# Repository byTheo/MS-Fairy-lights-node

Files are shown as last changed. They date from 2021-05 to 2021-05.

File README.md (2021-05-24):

# MS-Fairy-lights-node
A MySensors node for controlling Fairy Light strings. For making the mounting of the node into a light fixture easier, I've created a small PCB which supports NRF24L01+ radios only. I've kept the footprint of the PCB as small as I could, but I used through hole components in those places where the values depend on the type of fairy light you use. I used a 3 * AA battery version which outputs 5v to the fairy light string. In my case there was an 18ohm resistor between the chip that controls the fairy lights and the positive side of the fairy lights string itself.

# Hardware
It is of course not necessary to order a PCB but it makes life much easier than soldering it to a prototype board manually. This version supports up to 3 fairy lights - I have a seasonable version in my mind - and you can connect a tactile switch and rotary encoder to it for manual operation. I think that being able to manually operate smart lightning is a design must. Your phone battery can be empty or your HA system might be malfunctioning, so in those cases you need to be able to manually operate it.

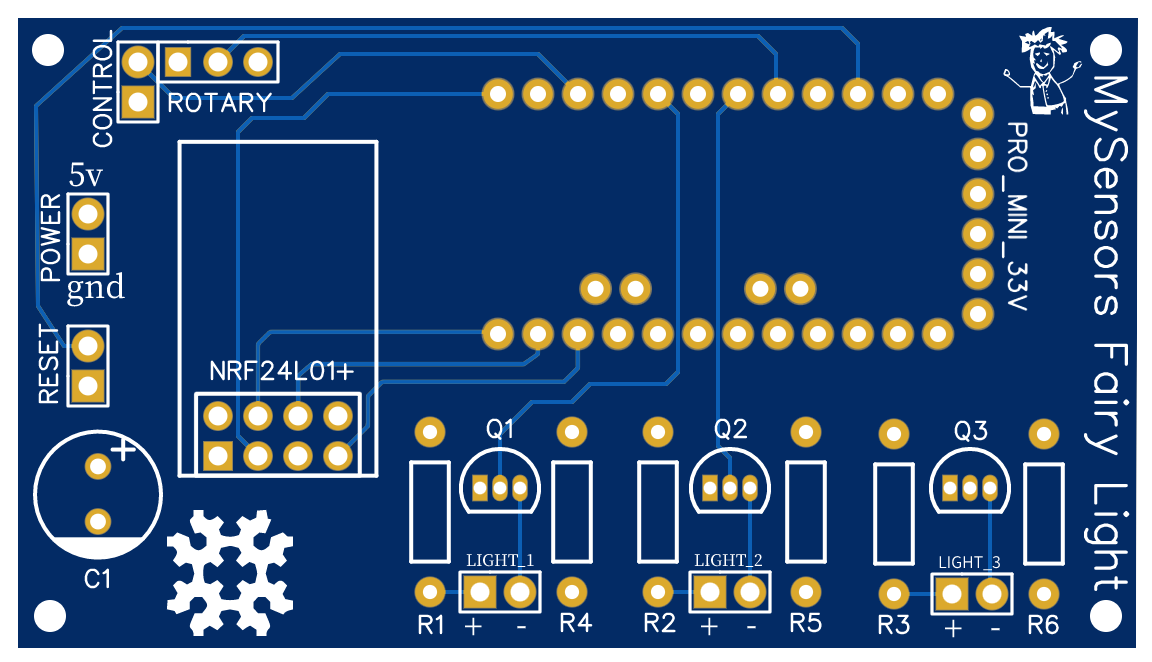
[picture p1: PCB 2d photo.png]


The mounting point for the NRF24L01+ radio is set inwards, this is so that an anglds female header (2*5p 2.54mm) can be mounted. I needed the radio to be mounted angled - but you will see that in a picture.

The Gerber files can be found in the root of this repository - otherwise I couldn't get the OpenHardware to detect my Gerver and design files. You can order 5 pcb's for around 15 euro's including shipping and tax.

The parts you need are:
- 1 x th 100uf capacitor for stabalising the NRF24L01+
- 1 x NRF24L01+ radio (for communicating over the MySensors network)
- 1 proMini 3.3v - they can be order cheaply on aliExpress or Ebat. I used the 3.3v version so that I didn't need to mount a separate power regulater for the radio on the PCB.

Depending on your FairyLight string, you need the following parts for each string:
- 1 2N7000 th - this mosfet can drive 200mA. My fairylights consume about 40mA at max brightness so more than sufficient
- 22 ohm th resistor - this is for current limiting the fairy light string it works on 2m fairy lights strings that are powered by 3  * AA batteries
- 1K pull down resistor (TH) - for pulling down the 2n7000's gate (10K or 100K is also fine)

Optional:
- either one tactile switch if you don't want to be able to manually dim the lights
- or a rotary encoder with tactile switch encorparated.

# Software
All the embedded software I created for this board is located in the *software* directory of this repository. The directory contains several sketches that utilize the PCB and transform it into:
- FairyLightLamp : a node with one single - dimmable - light which results in a nice ambiance.

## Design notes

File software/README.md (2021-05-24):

This directory contains several sketches for the Arduino IDE that use the MS Fairy lighs node pcb.

- FairyLightLamp : a sketchs that uses one fairly lights string. It's a dimmable light, with manual operation in the form of a rotary encoder with momentary switch. This type f lightning gives a nice ambiance but it's not suitable as a main light.

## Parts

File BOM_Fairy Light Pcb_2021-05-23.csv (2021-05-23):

ID | Name | Designator | Footprint | Quantity | Manufacturer Part | Manufacturer | Supplier | Supplier Part | Price | JLCPCB Part Class
1 | 100uF | C1 | CAP-TH_BD8.0-P3.50-D1.0-FD | 1 | 50V 100uF 8X12 | ValuePro | LCSC | C2749 | 0.0327
2 | Rotary encoder | H1 | HDR-TH_3P-P2.54-V | 1 | Header2.54mm 1*3P | BOOMELE | LCSC | C49257 | 0.0171 | Extended Part
3 | NRF24L01 | MK1 | WIRELM-SMD_NRF24L01 | 1 | NRF24L01+功率加强版绑定2.4Gwireless module | Ai-Thinker | LCSC | C90751 | 1.0655 | Extended Part
4 | Control switch | P2 | HDR-TH_2P-P2.54-V-M | 1 | 2.54mm 1*2P | ReliaPro | LCSC | C36717 | 0.0068
5 | 2.54mm 1*2P | P1,P3,P4 | HDR-TH_2P-P2.54-V-M | 3 | 2.54mm 1*2P | ReliaPro | LCSC | C36717 | 0.0068
6 | Power supply | P5 | HDR-TH_2P-P2.54-V-M | 1 | 2.54mm 1*2P | ReliaPro | LCSC | C36717 | 0.0068
7 | Reset switch | P6 | HDR-TH_2P-P2.54-V-M | 1 | 2.54mm 1*2P | ReliaPro | LCSC | C36717 | 0.0068
8 | 2N7000 | Q1,Q2,Q3 | TO-92-3_L4.9-W3.7-P1.27-L | 3 | 2N7000 | CJ | LCSC | C9114 | 0.0381 | Extended Part
9 | 18ohm | R1,R2,R3 | R_AXIAL-0.4 | 3
10 | 1K | R4,R5,R6 | R_AXIAL-0.4 | 3
11 | ARDUINO_PRO_MINI | U1 | ARDUINO_PRO_MINI | 1

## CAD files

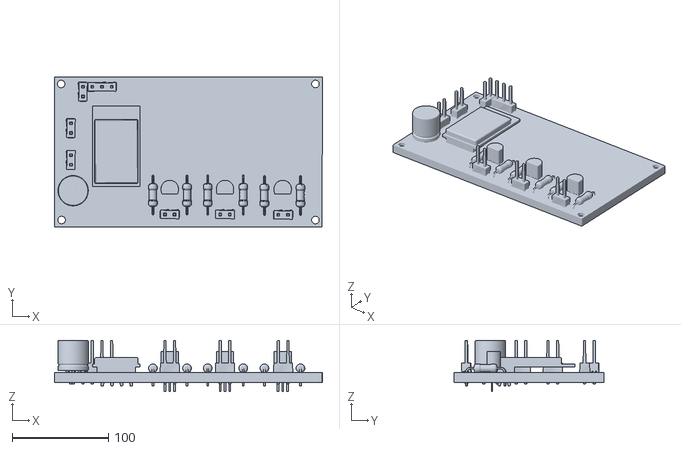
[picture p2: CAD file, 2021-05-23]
OBJ_MS_Fairy light - angled NRF24L01.obj
278.8 x 156.3 x 53.2

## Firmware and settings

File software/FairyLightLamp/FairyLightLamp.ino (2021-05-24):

/*
   My Sensos Sketch for the fair ligh based lamp, with smooth transition animation,

   By Theo
   January 4th 2021

   Revision
   01-04-2021 - initial version

   Future notes for myself - for a future project that uses a dimmer:
   - Handling Domoticz messages:
      only adjust brightness. Don't listen to brightness 0
      when V_LIGHT is 1, send current brightness. Domoticz turns on with 100% but it doesn't report it to the node
   - Handling user input:
      send current brightness when the lamp is turned on after sending V_LIGHT 1 ( "1" is on and "0" is off )
      send new brightness after user changes it.
*/

#include <Bounce2.h>
#include <Encoder.h>
#include "ledAnimation.h"
#include "multiClick.h"
#include "config.h"

const uint8_t POWER_SWITCH_PIN = 7; // Interupt pin so the sketch can wake up
const uint8_t LEDSTRING_PIN = 5; // Interupt pin so the sketch can wake up
const uint8_t ENCODER_FIRST_PIN = 2; // The first pin of the encoder, we use an interrupt pin for faster reading
const uint8_t ENCODER_SECOND_PIN = 4; // The second pin of the encoder, no more interrups left, but we should be able to wake up with just one
const uint8_t ENCODER_INCREMENTS = 4; // the amount of increments per encoder position

// Hardware definitions
Encoder *encoder; // encoder( ENCODER_FIRST_PIN, ENCODER_SECOND_PIN );  // The rotary encoder

SoftDebouncedMultiClick *powerSwitch; //( POWER_SWITCH_PIN );

AnimationManager animations( LEDSTRING_PIN  );

unsigned long currentMillis; // Used to pass the millis() value to different function so we don't have to call it too many times.
                              // that way we get shorter loop durations.
unsigned long lastTimeHBSent;


// Initializing the sketch
void setup() {

  encoder = new Encoder( ENCODER_FIRST_PIN, ENCODER_SECOND_PIN );  // The rotary encoder
  powerSwitch = new SoftDebouncedMultiClick( POWER_SWITCH_PIN );

  // Setup led output pin doesn't need a pinMode we're using pwm
  turnLightsOff();

  uint8_t storedBrightness = loadState( EEPROM_DIM_LEVEL_LAST );
  lightBrightness = storedBrightness == 255 ? DimmerDefaultValue : storedBrightness;
  oldEncoderPosition = lightBrightness * ENCODER_INCREMENTS;

  assignBrightnessLevelToEncoder();

  powerSwitch->setKeyPressHandler( handlePowerSwitchPressed );
  powerSwitch->setKeyClickHandler( handlePowerSwitchClicked );

  lastTimeHBSent = millis() - HEART_BEAT_INTERVAL;
}

// We only respond to a long press when the lamp is on so we can give the user feedback that he/she can release the switch.
// We use the long press to store the current brightness. Which will always be used when turning the lamp manually on
void handlePowerSwitchPressed( KEY_SCAN_STATES type, uint8_t amount, SoftDebouncedMultiClick source ) {
  if ( type == KP_LONG_PRESS && powerState ) {
    saveState( EEPROM_DIM_LEVEL_LAST, lightBrightness );
    animations.startBoundaryReachedAnimation();
  }
}

// Handler for normal clicks. Regardless of the amount of clicks. We always toggle the power.
// In the future we can implement double clicks and even tripple clicks to change the mode when
// the lamp is on.
void handlePowerSwitchClicked( KEY_SCAN_STATES type, uint8_t amount, SoftDebouncedMultiClick source ) {
  if ( type == KP_SHORT_PRESS_SEQUENCE ) {
    toggleLightState();
  }
}

void loop() {
  currentMillis = millis();

  if ( currentMillis - lastTimeHBSent >= HEART_BEAT_INTERVAL ) {
    lastTimeHBSent = currentMillis;
    sendHeartbeat();
    Serial.println( "Heartbeat send" );    
  }
  
  animations.checkAnimation( currentMillis );
  powerSwitch->checkSwitch( currentMillis );

  checkEncoder();
}


/*                   Routines for handling changes to the power state of the lamp    */

/*
  Turns on the fairy light led string with an animated fade to the current brightness level.
*/
void turnLightsOn() {
  animations.fadeToBrightnessLevel( map( lightBrightness, MIN_BRIGHTNES, MAX_BRIGHTNESS, 10, 255  ) );
}

/*
  Turns off the fairly led string.
*/
void turnLightsOff() {
  animations.fadeToBrightnessLevel( 0 );
}

/*
  Assigns the given brightness as the new brightness, if and only if the new brightness differs from the current brightness.
*/
void setNewLightBrightness( uint8_t newLightBrightness ) {
  if ( lightBrightness != newLightBrightness ) {
    if ( !powerState ) {
      powerState = true;
    }

    lightBrightness = newLightBrightness;
    turnLightsOn();
  }
  else {
    if ( !powerState ) {
      powerState = true;
      turnLightsOn();
    }
  }
}

/*
  Tries to assign to given state as the current state.
  If possible it will change the state accordingly.
*/
void setLightState( bool newState ) {
  if ( newState != powerState ) {
    powerState = newState;
    if ( powerState ) {
      turnLightsOn();
    }
    else {
      turnLightsOff();
    }
  }
}

/*
  Toggles the state of the lamp and sends the states to the gateway.
*/
void toggleLightState() {
  setLightState( !powerState );
  sendPowerstateToGateWay();
}


/*                Rotary encoder code    */

/*
  Scans for changes made by the user to the rotary encoder. And handles them accordingly.
*/
void checkEncoder() {
  newEncoderPosition = encoder->read();

  if ( newEncoderPosition != oldEncoderPosition ) {
    oldEncoderPosition = newEncoderPosition;
    if ( oldEncoderPosition % ENCODER_INCREMENTS == 0 ) {

      newBrightness = oldEncoderPosition / ENCODER_INCREMENTS;
      if ( newBrightness != lightBrightness ) {
        if ( newBrightness < MIN_BRIGHTNES ) {
          oldEncoderPosition = MIN_BRIGHTNES * ENCODER_INCREMENTS;
          assignBrightnessLevelToEncoder();
          // signal the user that the min brightness level has been reached
          animations.startBoundaryReachedAnimation();
        }
        else if ( newBrightness > MAX_BRIGHTNESS ) {
          oldEncoderPosition = MAX_BRIGHTNESS * ENCODER_INCREMENTS;
          assignBrightnessLevelToEncoder();

          // signal the user that the max brightness level has been reached
          animations.startBoundaryReachedAnimation();
        }
        else {
          if ( !powerState ) {
            // don't adjust brightness
            oldEncoderPosition = lightBrightness * ENCODER_INCREMENTS;
            assignBrightnessLevelToEncoder();
            setLightState( true ); // turn on the led

            sendPowerstateToGateWay();
          }
          else {
            setNewLightBrightness( oldEncoderPosition / ENCODER_INCREMENTS );
            sendBrightnessLevelToGateWay();
          }
        }
      }
    }
  }
}

void assignBrightnessLevelToEncoder() {
  encoder->write( lightBrightness * ENCODER_INCREMENTS  );
}



/*            MySensors specific code    */


/*
   Prestent the MySensors node to the Gateway. This includes the sketch name and -version as well as the childs of the node
*/
void presentation() {
  sendSketchInfo( MS_SketchName, MS_SketchVersion );
  delay( 50 ); // Let's not DDOS the Gateway
  present(  CHILD_ID_LIGHT, S_DIMMER );
  delay( 50 );
  send( dimmerMsg.set( (int)map( lightBrightness, MIN_BRIGHTNES, MAX_BRIGHTNESS, 1, 100 ) ) ); // Send the stored brightness value to the Gateway
  delay( 50 ); // When the node is closer to the gateway it doesn't receive it's current state, which I can not explain. But using delays works
              // A best practice would be to use random delays, chosen once at the start of the method. The delay would be 40 - 80ms
              // if all nodes do this it will give them all time to connect to the gateway after a power out. The Sonoff once had a
              // power out in production, and when the came back on all the sonoff Devices where literally DDOS-ing the Sonoff servers whilst
              // thrying to connect to it.
  request( CHILD_ID_LIGHT, V_LIGHT );
}

/*
  Event handler for handling message received from the gateway.
*/
void receive( const MyMessage &message ) {
//  Serial.print( "Received message for node id " ); Serial.println( getNodeId() );
  // We only accept messages for this node
  if (message.destination == getNodeId()) {
    if ( message.type == V_DIMMER ) {
      int dimvalue = atoi( message.data );
      if ( dimvalue  > 0 && dimvalue <= 100 ) {
        setNewLightBrightness( converFromMySensorsBrightness( dimvalue ) );
        assignBrightnessLevelToEncoder();
      }
    }
    else if ( message.type == V_LIGHT ) {
      int value = atoi( message.data );
      setLightState( value == 1 );
      if ( value == 1 ) {
        delay( 10 );
        sendBrightnessLevelToGateWay();
      }
    }
  }
}

/*
  THis method is called before any hardware. In here we can add the power saving code.
*/
void before() {
  // Initialize all out pins written to low. So that all unused pins will not use any power
  for ( uint8_t cnt = 0; cnt <= 19; cnt++ ) {
    if ( cnt == 8 ) { // Don't pull the spi pins low. They're used by MySensors
      cnt = 13;
      return;
    }
    pinMode( cnt, OUTPUT );
    digitalWrite( cnt, LOW );
  }

  // disable ADC
  ADCSRA = 0;  
}

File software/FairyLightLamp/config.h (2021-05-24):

// Enable debug prints, uncomment to watch the MySensors debug log.
//#define MY_DEBUG

// Comment to turnof Serial communication (saves space) comment it when you want to debug.
//#define MY_DISABLED_SERIAL

// Set the wait for ready to zero if you want the light the be operable even when the Gateway is off.
//#define MY_TRANSPORT_WAIT_READY_MS 0


// Enable and select radio type attached
#define MY_RADIO_NRF24
//#define MY_NODE_ID 21 // This is the development node ID. I think we should port it to the first protottype as well.

#include <SPI.h>
#include <MySensors.h>

#define MS_SketchName "FairyLight lantern"
#define MS_SketchVersion "1.0"

#define CHILD_ID_LIGHT 1

const uint8_t EEPROM_DIM_LEVEL_LAST = 1;
const uint8_t DimmerDefaultValue = 5;

MyMessage lightMsg( CHILD_ID_LIGHT, V_LIGHT );
MyMessage dimmerMsg( CHILD_ID_LIGHT, V_DIMMER );

// Definitions for the light level
const uint8_t MIN_BRIGHTNES = 1;
const uint8_t MAX_BRIGHTNESS = 15; // 15 level lamp means around 17 pwm steps per level (since we start at 10)

const uint8_t MIN_MYSENSORS_BRIGHTNES = 1;
const uint8_t MAX_MYSENSORS_BRIGHTNESS = 100; // 15 level lamp means around 17 pwm steps per level (since we start at 10)


// Variables for storing the current state of power, brightness and the controls.
bool    powerState = false; // false means light off, true means light on
uint8_t lightBrightness, newBrightness; // the brightness and the potential new brightness
long oldEncoderPosition, newEncoderPosition; // The last read encoder position and the potential new position
bool switchStateUpdated; // Indicates wether or not the state of the power switch has been changed,

const unsigned long HEART_BEAT_INTERVAL = 1800000; // We send a heart beat ruffly each half hour

/*
 Returns the given gateway brightness to the lamps brightness level.
 The lamp doesn't support 1-100 by design. Because it's really anoying having to turn a
 rotary encode 100 times to go from max to low or the other way arround. 15 brightness levels seem
 to be good enough. Which can all be changed by changing the constants in this file.
 */
uint8_t converFromMySensorsBrightness( int aBrightness ) {
  return map( aBrightness, MIN_MYSENSORS_BRIGHTNES, MAX_MYSENSORS_BRIGHTNESS, MIN_BRIGHTNES, MAX_BRIGHTNESS );
}

/*
 Returns the current light brightness converted to the gateway brightness (Domotiz supports 1-100)
 */
uint8_t getConvertedMySensorsBrightness() {
  return map( lightBrightness, MIN_BRIGHTNES, MAX_BRIGHTNESS, MIN_MYSENSORS_BRIGHTNES, MAX_MYSENSORS_BRIGHTNESS );
}

/*
 Sends the current brightness level to the gateway when e.g. the user changed the brightness manually.
 */
void sendBrightnessLevelToGateWay() {
  send( dimmerMsg.set( (int)getConvertedMySensorsBrightness() ) ); // Send the stored brightness value to the Gateway
}

/*
 Sends the current power state to the gateway. If the current power state is on (true), the current brightness level is also
 send, because domoticz will set the brightness to full when a dimmer is turned on. Don't know if this is by design (I use a very old
 Domoticz version) or if it's a bug. But it's certainly anoying. But resending the current brightness syncs the domoticz brightness
 level to what was stored on the lamp.
 */
void sendPowerstateToGateWay( ) {
  send( lightMsg.set( powerState == true ? "1" : "0" ) );

  if ( powerState ) {
    delay( 15 ); // Delay is for preventing ddos effect on Gateway and to give the antenna more time to recover. 
    sendBrightnessLevelToGateWay(); // Domotics sets the brightness to max when it turns on a dimmer. It doesn't go back to the previous,
                                     // So in this case we use the stored users brightness
  }
}
